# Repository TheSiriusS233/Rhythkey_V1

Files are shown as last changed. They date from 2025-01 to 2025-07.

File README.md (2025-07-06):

# Introduction

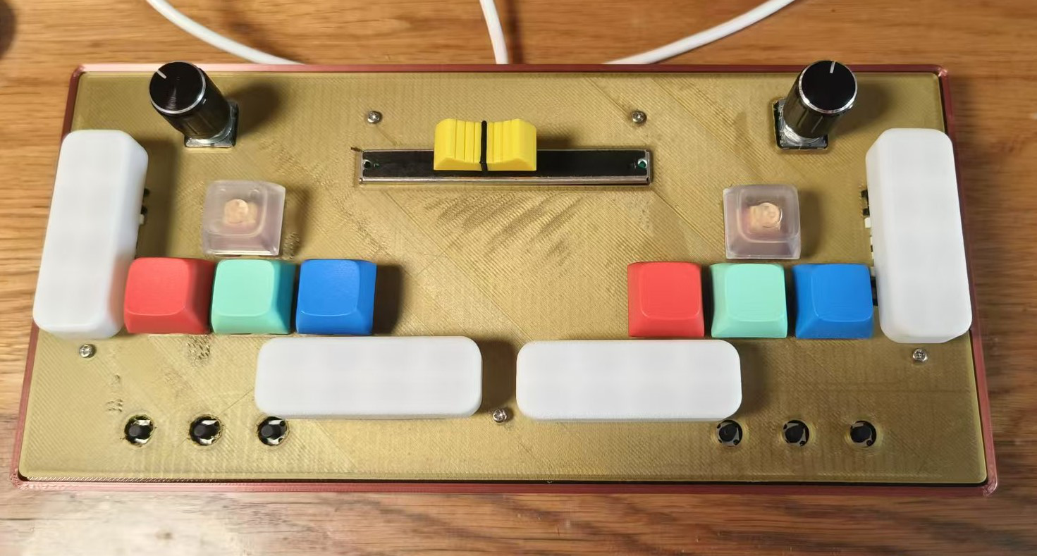
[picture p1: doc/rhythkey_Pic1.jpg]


Rhythkey is a versatile music game controller which use Keyboard Simulation and mouse simulation. The controllor used in this project is arduino pro micro.
This controller consist 12 keys (recommand: 8 1U sized keys and 2 2.75U sized side-keys), 6 switches, 2 encoders and 1 potentiometers.

All key switches and encoder can be programmed to be uses as one character output within ASCII II. Additionally, the potentiometer and encoders can be programmed to
control the mouse movement.

This controllor is designed for play multiple music games, for example: **Ongeki, Sound Voltex, DJMAX, Muse Dash, Musynx, Osu!mania, Osu!, Osu!taiko, Osu!catch, 	Hatsune Miku: Project Diva...**

# Structure
This game controllor is construct from following conponents:
main part:
* 1x 3D printed top cover plate ("board_up.STL" in rhythkeyV1_CAD folder)
* 1x 3D printed bottom plate ("board_bottom.STL" in rhythkeyV1_CAD folder)
* 1x PCB board ("RhythkeyV1_Gerber.zip")
* 1x Sparkfun Arduino Pro Micro (https://www.sparkfun.com/pro-micro-3-3v-8mhz.html)
* 12x mechanical key_Switches
* 12x hotswap Socket Kailh for hotswap keyboard
* 8x 1U sized keycaps and 4 2.75U keycaps
* 4x Satellite Axis for 2.75 U keys.

electronics:
* 2x Incremental Encoders (EC11E09244BS) (with 2 knobs)
* 1x B10K 75mm Slide Potentiometer (with knob)
* 6x N.O.(Normally Open) Pushbutton Switches (with knobs)
* 10x R0805 10K ohm resistors
* 4x R0805 100nF capacitors
* 3x SMA_1N4007 diode
* 2x 2.54mm Pitch (1x12) Female Headers

other mechanical parts:
* 6x M2x8 Self-tapping screw
* 5x M2x16 Self-tapping screw

# How to build this project?
step 1: preparing the material
* download the STL files of the 3D printed board, and print them
* download the Gerber file of PCB, and contact a PCB factory for manufacturing.

step 2: soldering
* for this step, you need a soldering set to proceed.
* for the PCB schematic, please refer to rhythkeyV1_Schematic.pdf
* top layer:
  * resistors R1 - R10
  * capacitor C1 - C4
  * Diode D1 - D3
  * Slide Potentiometer
  * Incremental Encoders
  * Pushbutton Switches
* bottom layer:
  * hotswap Socket Kailh for hotswap keyboard
  * Female Headers
 * after soldering, your PCB board should looks like this:
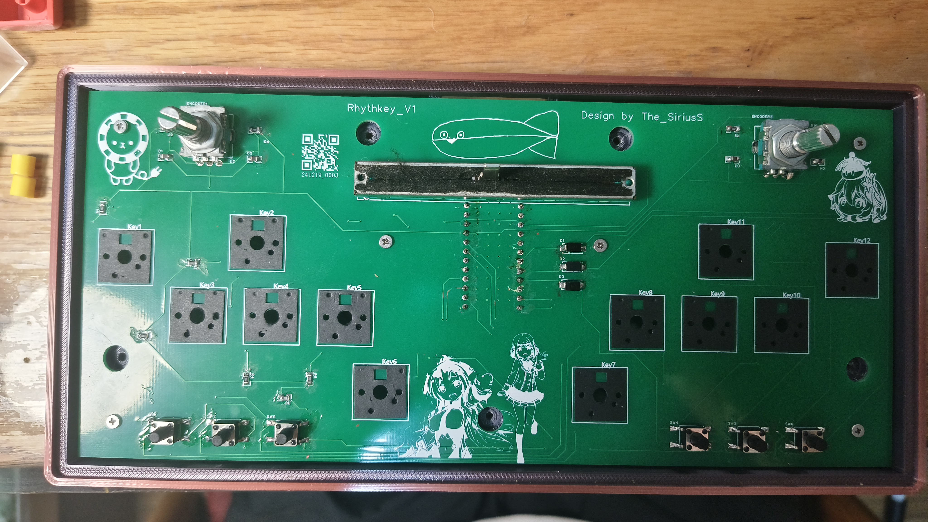
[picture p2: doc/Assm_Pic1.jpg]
   
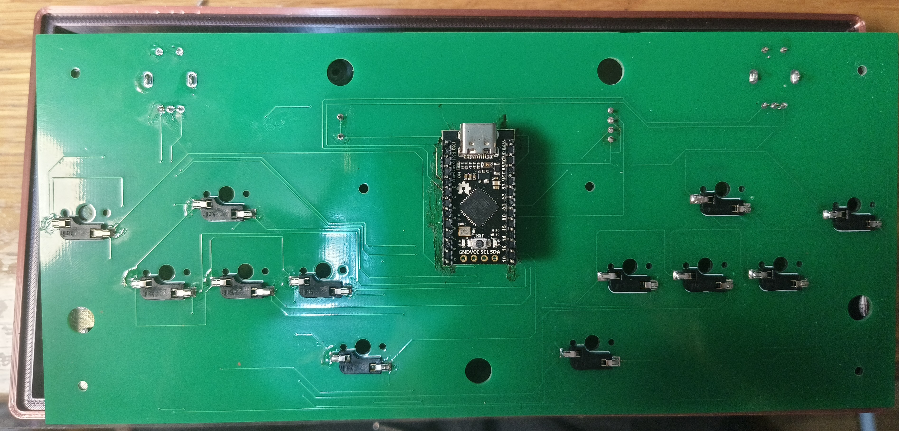
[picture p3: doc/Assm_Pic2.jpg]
   
   
Step 3: Assembly
 1. After soldering, fix the PCB on the bottom plate with 6 M2x8 Self-tapping screws
 2. Put Satellite Axis into the slot of top plate.
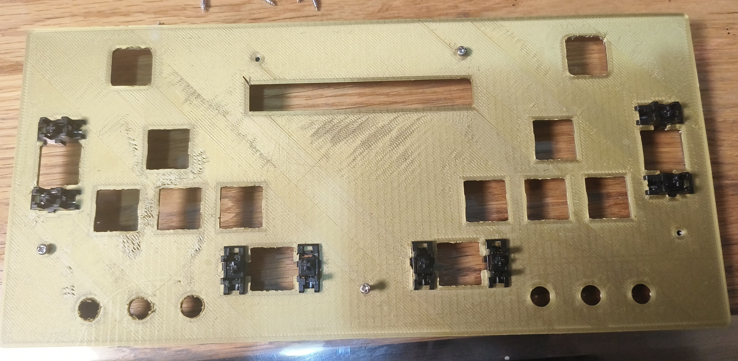
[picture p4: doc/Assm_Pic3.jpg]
    
 3. Fix the top plate with 5 M2x16 Self-tapping screws
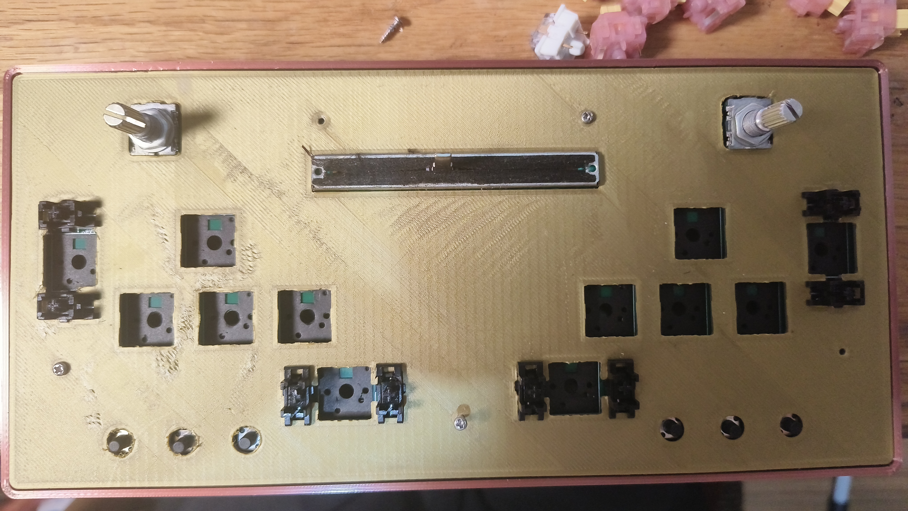
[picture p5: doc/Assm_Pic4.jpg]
    
 4. Insert 12 mechanical key_Switches in the slot of top plate.
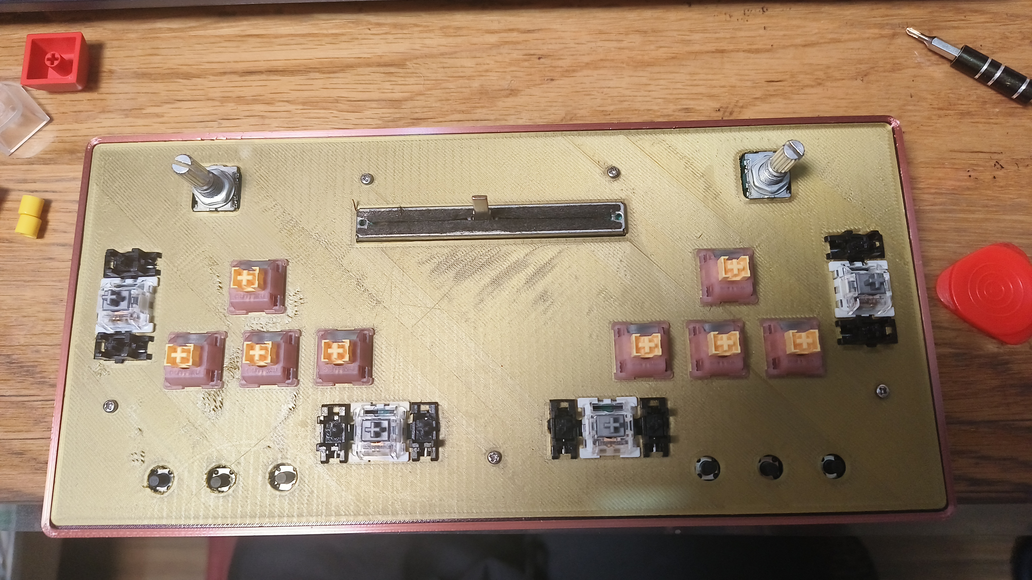
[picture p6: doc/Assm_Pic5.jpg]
    
 5. Put the keycaps and knobs on corresponding parts.
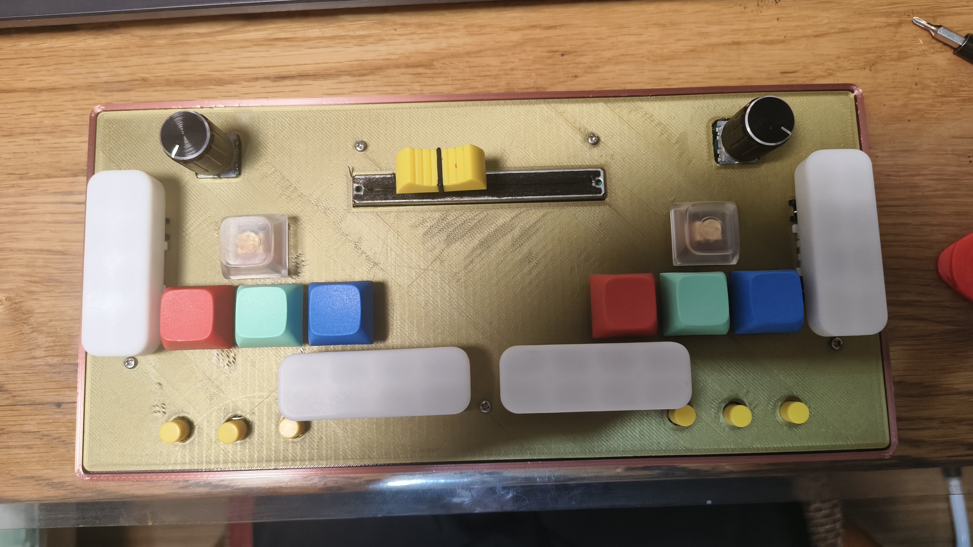
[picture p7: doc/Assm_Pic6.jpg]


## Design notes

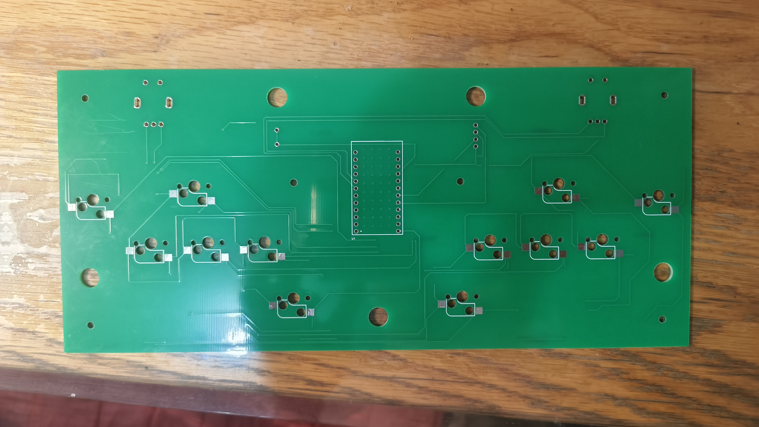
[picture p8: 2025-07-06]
doc/PCB_Pic2.jpg

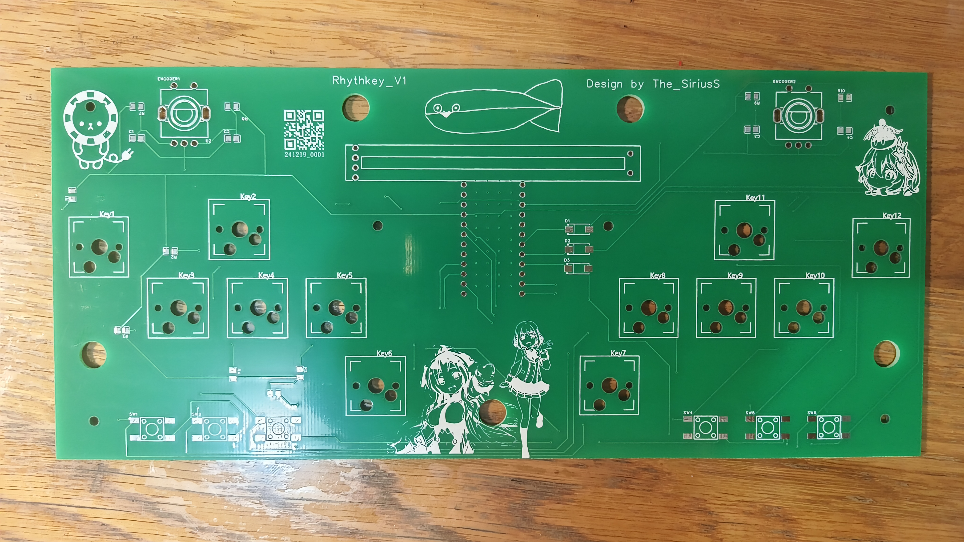
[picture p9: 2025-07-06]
doc/PCB_Pic1.jpg

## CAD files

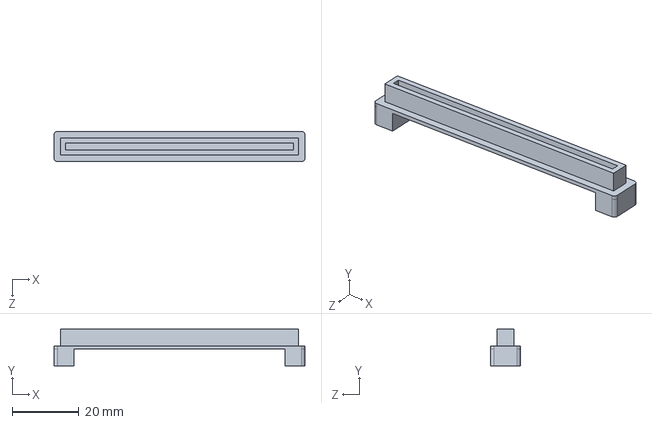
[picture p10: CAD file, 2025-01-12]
rhythkeyV1_CAD/potentiometer_slider.SLDPRT
75.0 x 11.0 x 9.00 mm

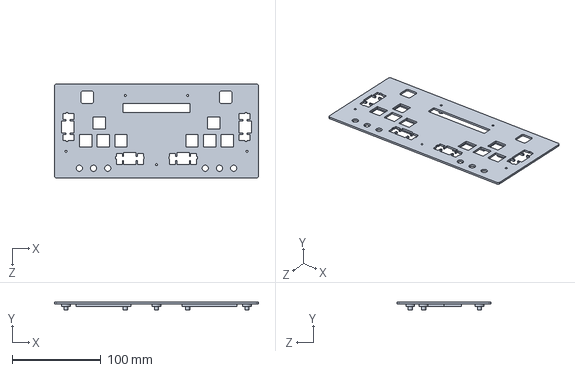
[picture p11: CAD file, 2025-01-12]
rhythkeyV1_CAD/board_up.SLDPRT
230.0 x 9.00 x 106.0 mm

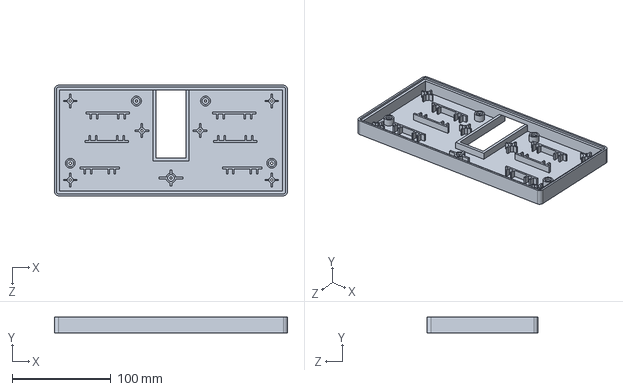
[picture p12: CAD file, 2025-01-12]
rhythkeyV1_CAD/board_bottom.SLDPRT
236.0 x 16.0 x 112.0 mm

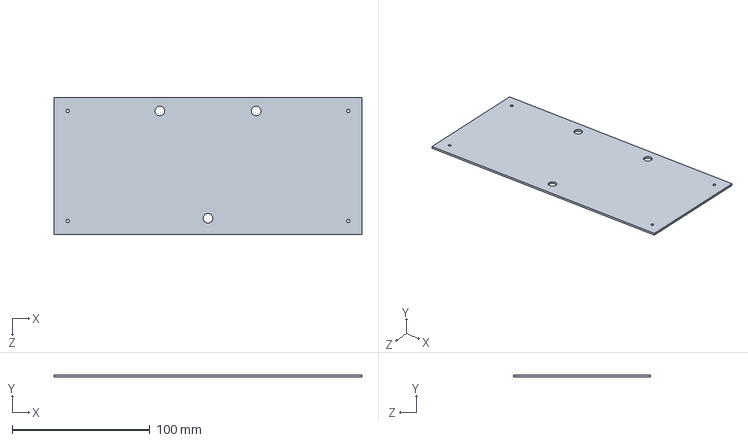
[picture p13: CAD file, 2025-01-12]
rhythkeyV1_CAD/PCB_subtitute.SLDPRT
224.0 x 1.60 x 100.0 mm

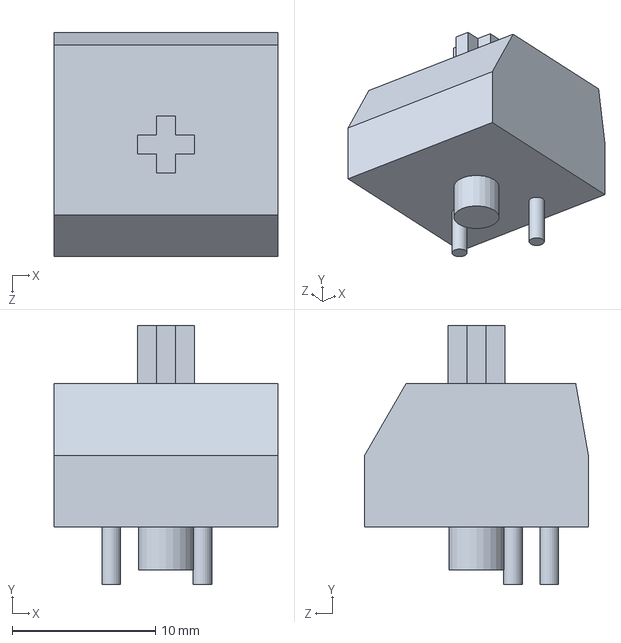
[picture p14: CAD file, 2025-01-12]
rhythkeyV1_CAD/keyboard_switch.SLDPRT
15.6 x 18.1 x 15.6 mm

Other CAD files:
rhythkeyV1_CAD/rhythkey_PCB_LCEDA.step
rhythkeyV1_CAD/board_bottom.STL
rhythkeyV1_CAD/board_up.STL

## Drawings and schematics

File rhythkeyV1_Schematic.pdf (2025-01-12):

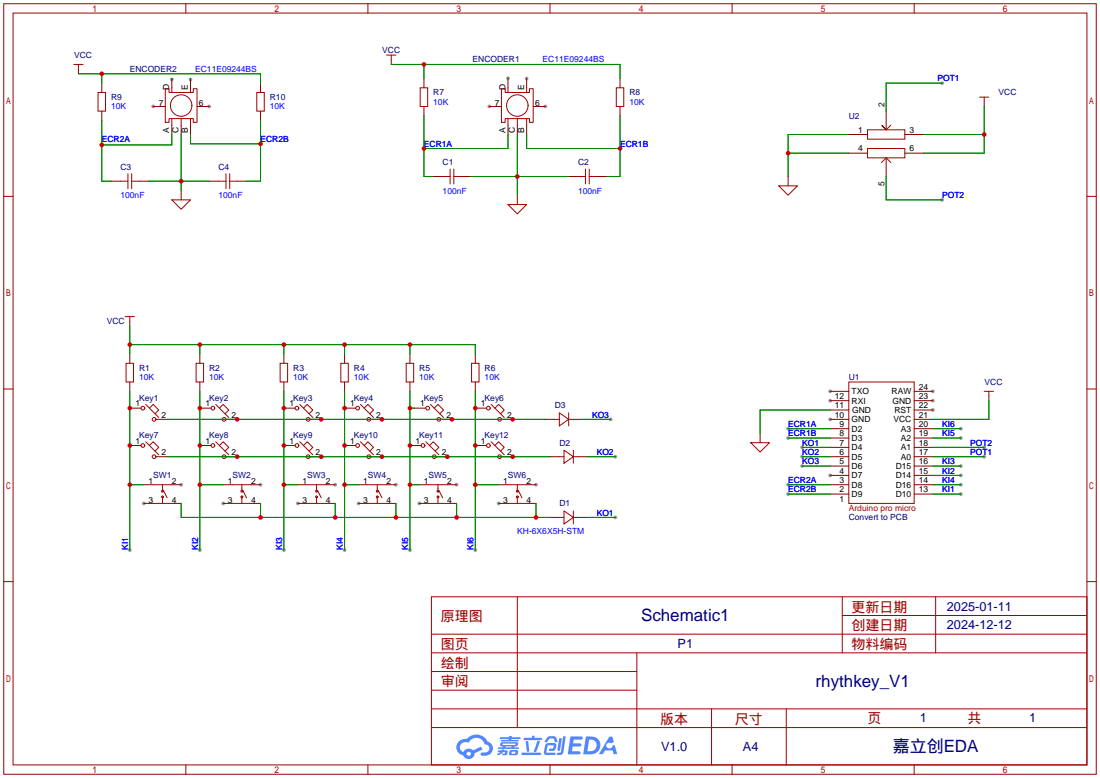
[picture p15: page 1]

D10 13 D16 14 D14 15 D15 16 A0 17 A1 18 A2 19 A3 20 VCC 21 RST 22 GND 23 RAW 24

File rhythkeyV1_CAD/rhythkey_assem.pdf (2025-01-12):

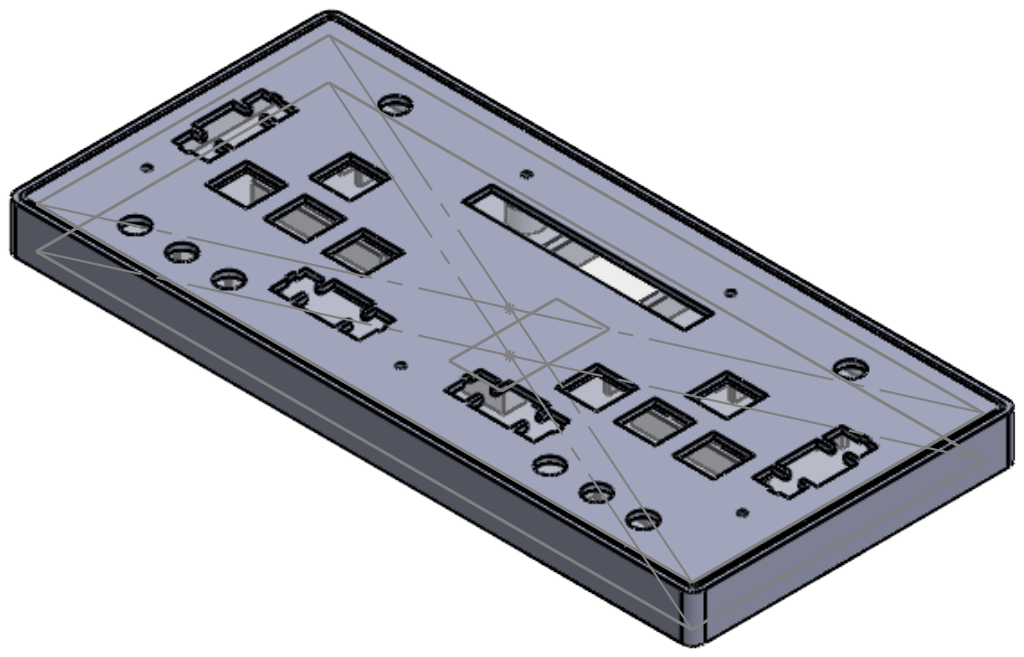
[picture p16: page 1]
UNITS: mm; UNITS: in; ANGLES; DWN BY:; REV; SIYUAN WANG

PROJECT: | DRAWING: Sheet1

UNLESS OTHERWISE NOTED: | | SIZE A4

SURFACE
1.6 Pm | X.XX +/- .10 X.X +/- .20 X +/- .50 | X.XXX +/- .005 X.XX +/- .01

MATERIAL: | QTY:
DATE: | UNITS: | SCALE: 1:3 | SHEET 1 OF 5

SOLIDWORKS Educational Product. For Instructional Use Only.

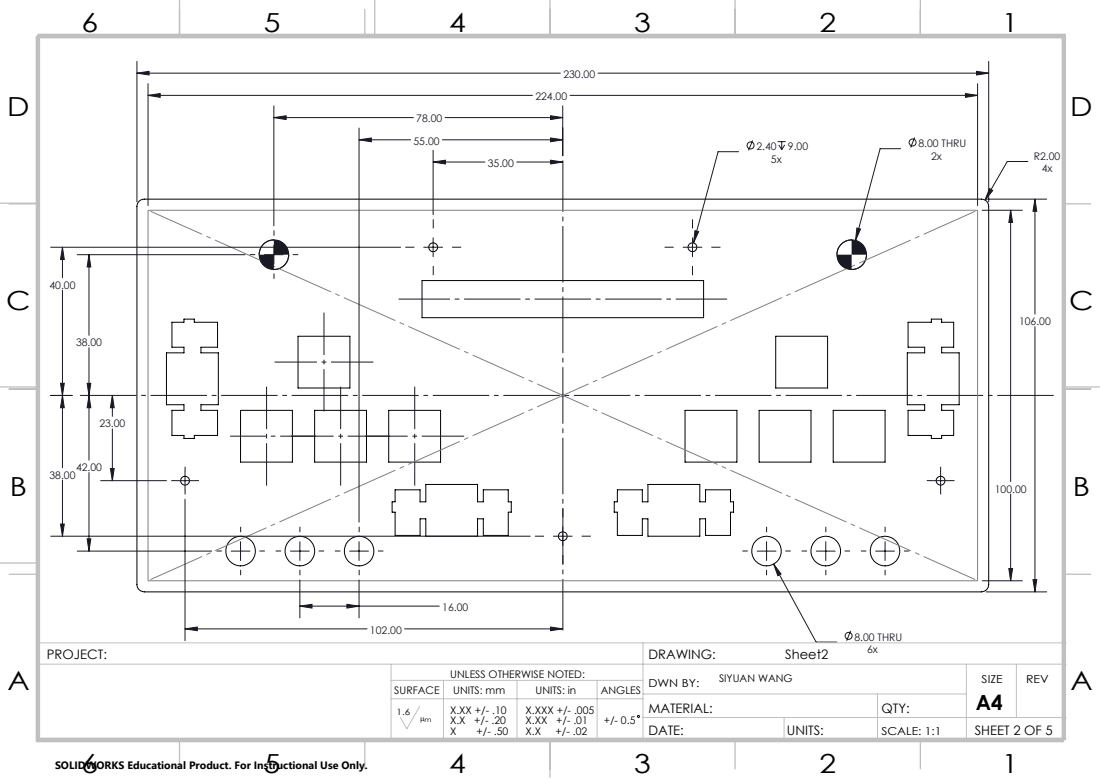
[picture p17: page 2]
8.00 THRU; UNITS: mm; UNITS: in; ANGLES; DWN BY:; REV; SIYUAN WANG

PROJECT: | 6x DRAWING: Sheet2

UNLESS OTHERWISE NOTED: | | SIZE A4

SURFACE
1.6 Pm | X.XX +/- .10 | X.XXX +/- .005

MATERIAL: | QTY:

SCALE: 1:1

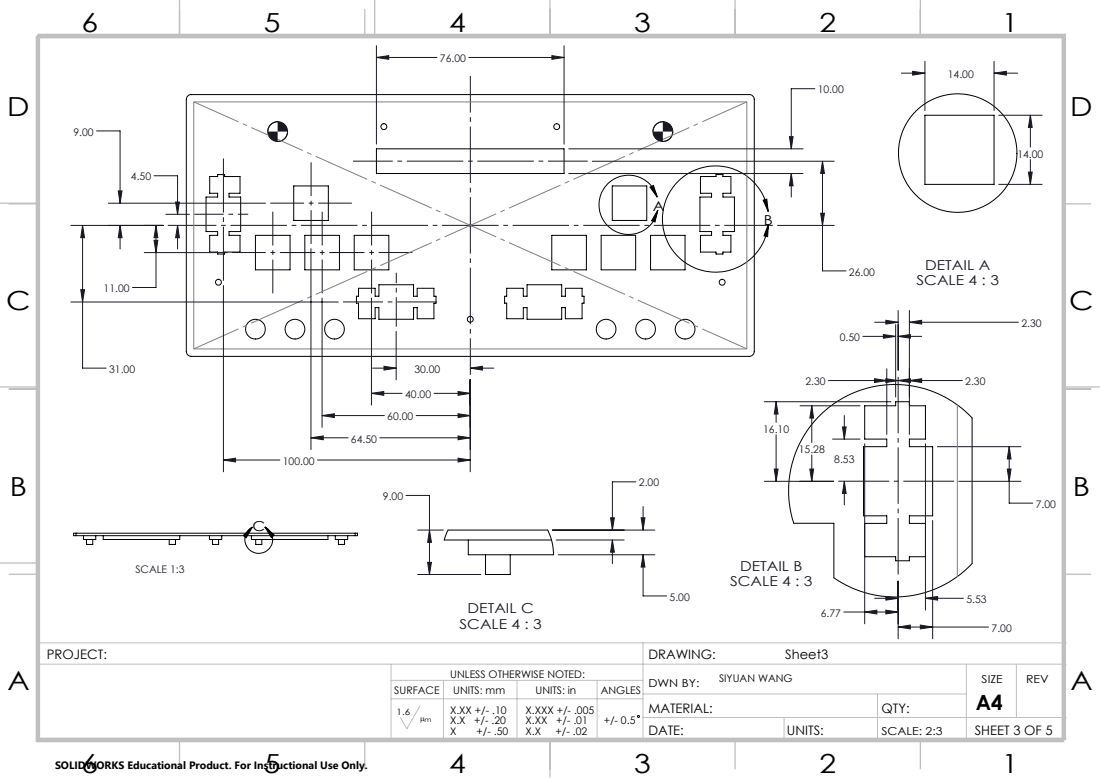
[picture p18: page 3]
DETAIL A SCALE 4 : 3; DETAIL B SCALE 4 : 3; SCALE 1:3; DETAIL C SCALE 4 : 3; UNITS: mm; UNITS: in; ANGLES; DWN BY:; REV; SIYUAN WANG

PROJECT: | DRAWING: Sheet3

UNLESS OTHERWISE NOTED: | | SIZE A4

SURFACE
1.6 Pm | X.XX +/- .10 | X.XXX +/- .005

MATERIAL: | QTY:

SCALE: 2:3

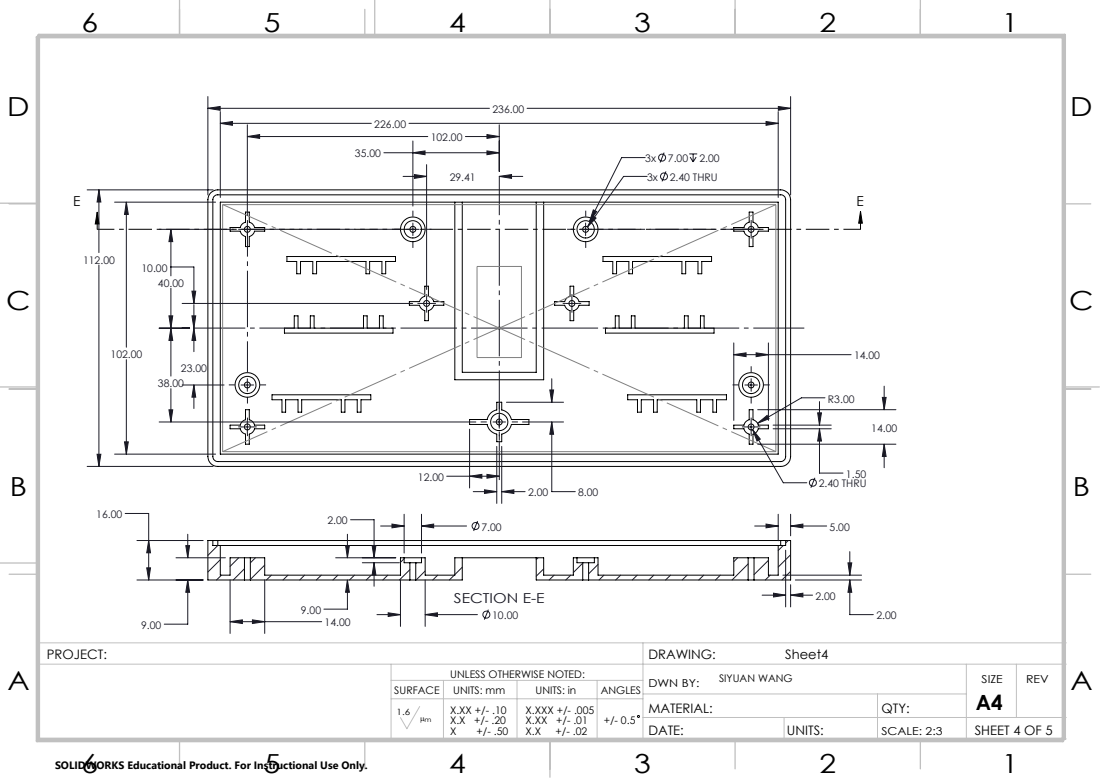
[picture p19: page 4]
2.40 THRU; 3x 7.00 2.00 3x 2.40 THRU; SECTION E-E; UNITS: mm; UNITS: in; ANGLES; DWN BY:; REV; SIYUAN WANG

PROJECT: | DRAWING: Sheet4

UNLESS OTHERWISE NOTED: | | SIZE A4

SURFACE
1.6 Pm | X.XX +/- .10 | X.XXX +/- .005

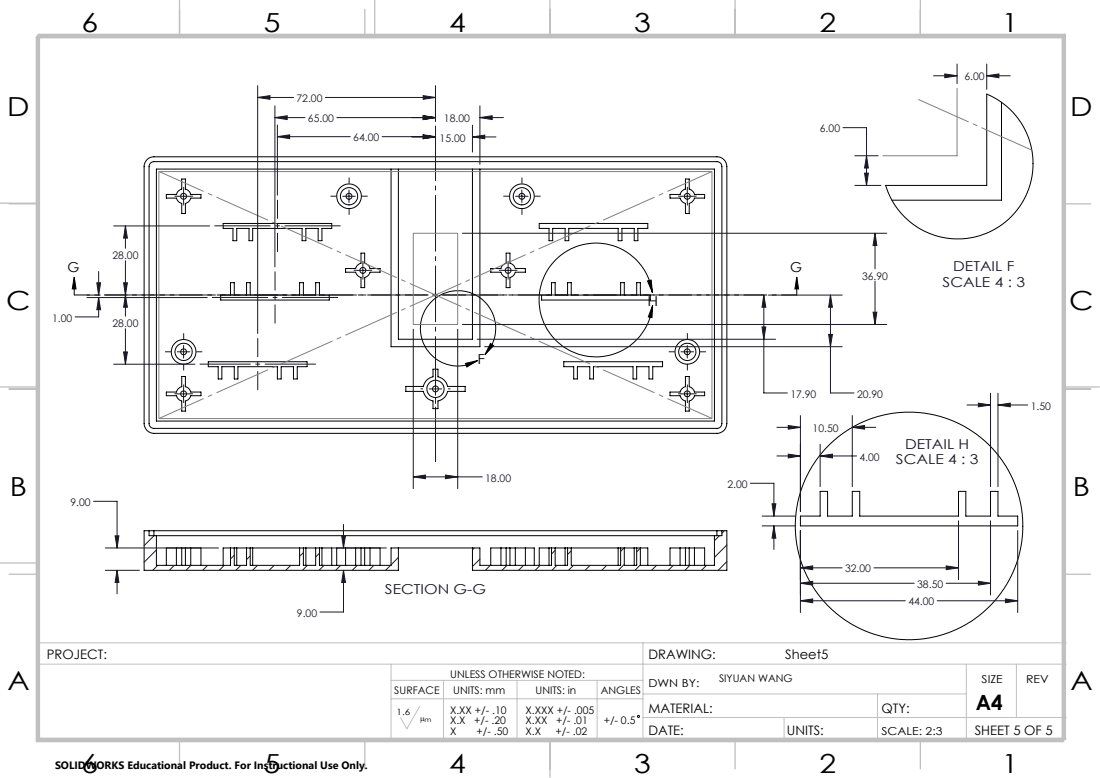
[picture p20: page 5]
DETAIL F SCALE 4 : 3; SECTION G-G; DETAIL H SCALE 4 : 3; UNITS: mm; UNITS: in; ANGLES; DWN BY:; REV; SIYUAN WANG

PROJECT: | DRAWING: Sheet5

UNLESS OTHERWISE NOTED: | | SIZE A4

SURFACE
1.6 Pm | X.XX +/- .10 | X.XXX +/- .005

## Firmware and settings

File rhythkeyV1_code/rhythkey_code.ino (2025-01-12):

//This code is write for testing a 2x5 key array on Arduino Pro micro.
//The testing result is used for buliding schematic for rhythm game keyboard project.


#include <Keyboard.h>
#include <Mouse.h>

char key_array[3][6] = {{65,66,67,68,85,79},
                        {74,75,79,76,76,80},
                        {81,83,74,68,68,70}};
byte row_index;
byte col_index;

bool button_state[3][6];
bool prev_state[3][6] = {{1, 1, 1, 1, 1, 1},
                         {1, 1, 1, 1, 1, 1},
                         {1, 1, 1, 1, 1, 1}}; //initialize previous button state.

int pot;
int pre_cursor_val;
//bool trig = 0;

void setup() 
{
  pinMode(10, INPUT_PULLUP);
  pinMode(16, INPUT_PULLUP);
  pinMode(14, INPUT_PULLUP);
  pinMode(15, INPUT_PULLUP);
  pinMode(A2, INPUT_PULLUP);
  pinMode(A3, INPUT_PULLUP);
  pinMode(4, OUTPUT);
  pinMode(5, OUTPUT);
  pinMode(6, OUTPUT);

  Serial.begin(9600);
}

void loop() 
{

  for(byte index=0;index<5;index++)
  {
    for (row_index = 0; row_index<3; row_index++)
    {
      digitalWrite(4,HIGH);
      digitalWrite(5,HIGH);
      digitalWrite(6,HIGH); // reset all OUTPUT pin as HIGH.
      digitalWrite(row_index+4,LOW); // assign the pin of current row as LOW. (current sink)

      //for column 0 (first column)
      button_state[row_index][0] = digitalRead(10); //read button state for column 0.
      check_button_state(button_state[row_index][0], prev_state[row_index][0], key_array[row_index][0]); // call function to give key output response.
      prev_state[row_index][0] = button_state[row_index][0]; //updating the previous state.

      //for column 1-3 (2nd-4st column)
      for(col_index = 1; col_index<4; col_index++)
      {
        button_state[row_index][col_index] = digitalRead(col_index+13); //read button state for column 1-3.
        check_button_state(button_state[row_index][col_index], prev_state[row_index][col_index], key_array[row_index][col_index]); // call function to give key output response.  
        prev_state[row_index][col_index] = button_state[row_index][col_index]; //updating the previous state. 
       
      }
      
    //for column 4 (5th column)
      button_state[row_index][4] = digitalRead(A2); //read button state for column 4.
      check_button_state(button_state[row_index][4], prev_state[row_index][4], key_array[row_index][4]); // call function to give key output respon
      prev_state[row_index][4] = button_state[row_index][4];

      //for column 5 (6th column)
      button_state[row_index][5] = digitalRead(A3); //read button state for column 4.
      check_button_state(button_state[row_index][5], prev_state[row_index][5], key_array[row_index][5]); // call function to give key output respon
      prev_state[row_index][5] = button_state[row_index][5];      
    }
  delay(2);
  //get the aveage output of potentiometer. 
  pot = pot + analogRead(A0); //get the 10 accumulated value of A0
  }
  pot = pot/5; //get the aveage value of pot
  //Serial.println(pot);
  pre_cursor_val = mouse_control(pot, pre_cursor_val);
  
}



int check_button_state (bool state, bool prev_state, int key)
{
  bool trig = 0;
  if (trig == 0)
  {
    if (state == LOW && prev_state == HIGH)
    {
        // and it's currently pressed:
      Keyboard.press(key);
      delay(5);
      
    }
    else if (state == HIGH && prev_state == LOW) 
    {
        // and it's currently released:
      Keyboard.release(key);
      delay(5);
      
    }
    else
    {
      
    }
  }
 
}

int mouse_control(int pot_ave, int prev)
{
  int cursor;

  cursor = int(1023.0-1079.0*(1023.0-pot_ave)/1023.0);

  if(pot_ave <= 1)
  {
    cursor = 0; //move cursor to the left boundary of screen.
    Mouse.move(-1079,0);
  } 
  else if (pot_ave >= 1020)
  {
    cursor = 1079; //move cursor to the right boundary of screen.
    Mouse.move(1079,0,0);
  }

  Mouse.move(cursor - prev,0,0);
  prev = cursor; // updating the previous cursor value.
  return prev;
}
